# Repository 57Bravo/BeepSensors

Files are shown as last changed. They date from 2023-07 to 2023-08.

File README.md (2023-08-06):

# BeepBerry Sensors Carrier

Integrates UBlox GPS, IMU/MAG, BARO, and buzzer.

REV: - was built and verified on a BeepBerry, however, there are some problems with it:
* During integration, I blew the TPS61030 boost converter IC. I ordered a couple from Mouser and was able to replace it, fixing the device. I was not able to identify what caused the failure in that IC though.
* The buzzer isn't very loud, but can be used as a generic audio device. It's kind of neat that you can use espeak to do text to speech on such a small piezo.
* The GPS antenna doesn't have a large enough ground plane, so 3D fixes break often. It's still usable, just not what you'd expect from a UBlox devkit.
* GPS acquisition eats the battery, but you can control the GPS reset line to disable it to save power. 



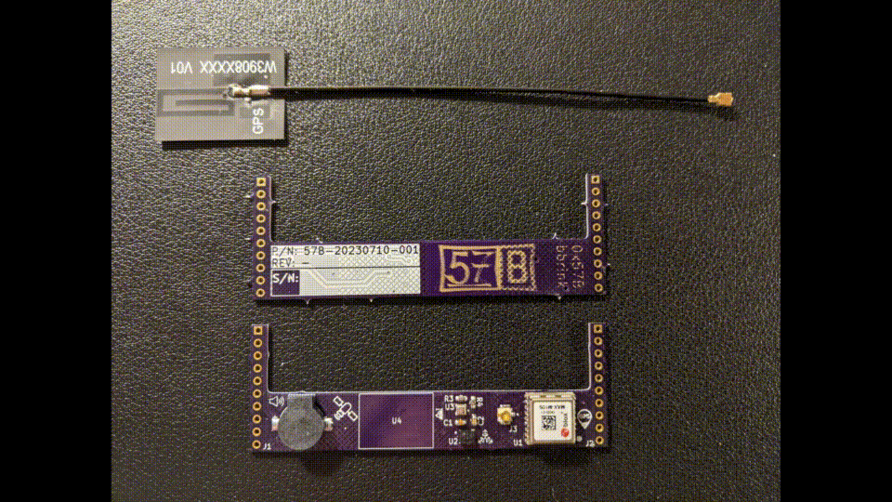
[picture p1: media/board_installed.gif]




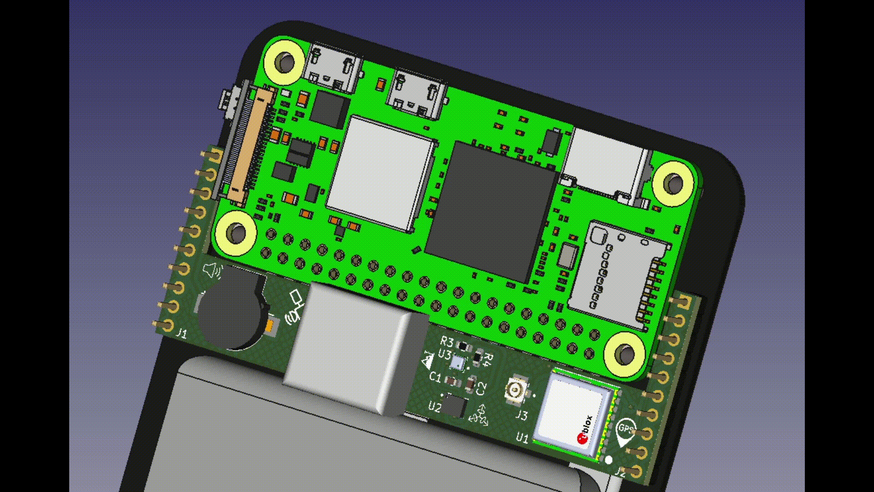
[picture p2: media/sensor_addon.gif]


## Using the buzzer

### Simple Tones
```
import RPi.GPIO as GPIO
import time
import random

GPIO.setmode(GPIO.BCM)
GPIO.setup(13, GPIO.OUT)

pwm = GPIO.PWM(13, 57)
pwm.start(10)

for i in range(random.randint(0,10)):
  pwm.ChangeFrequency(random.randint(1,10000))
  time.sleep(random.random())
pwm.stop()
```

### ALSA

In `/boot/config.txt`, add:

```
dtoverlay=audremap,enable_jack=on
dtoverlay=pwm-2chan,pin2=13,func2=4
```

then use anything that uses a sound card, IE:

`espeak "SAY SOMETHING"`

`aplay "some.wav"`

## Using GPS PPS

In `/boot/config.txt`, add:

`dtoverlay=pps-gpio,gpiopin=16`

This will allow you to use gpsd with `/dev/pps0`.

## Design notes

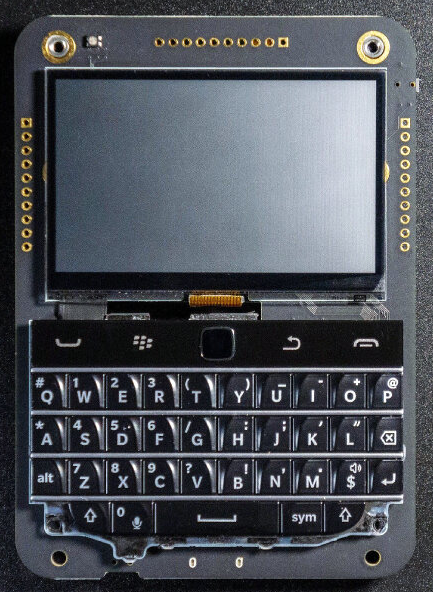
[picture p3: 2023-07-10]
media/beepberry.png

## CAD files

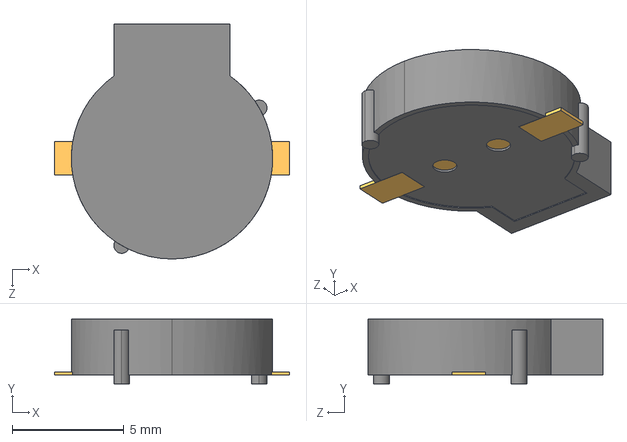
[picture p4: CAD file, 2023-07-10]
pcb/beepsensors/3d_models/CUI_DEVICES_CBT-09427-SMT-TR.step
10.5 x 2.90 x 10.5 mm

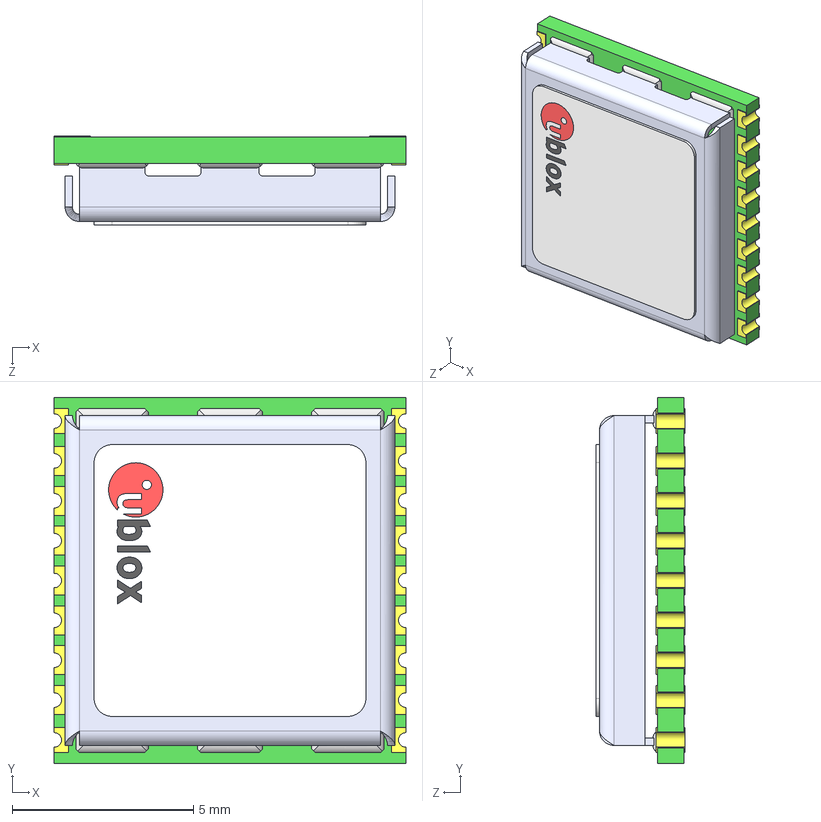
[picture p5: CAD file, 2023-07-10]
pcb/beepsensors/3d_models/max-7.step
9.70 x 10.1 x 2.47 mm
u-blox_MAX_label_Default
Shield
MAX_PCB

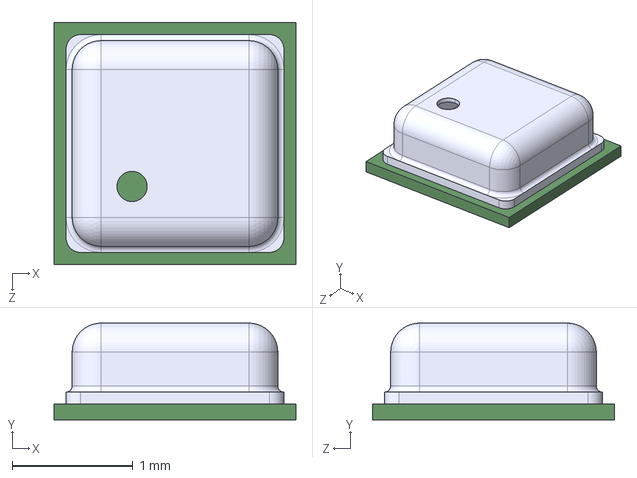
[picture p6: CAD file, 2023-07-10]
pcb/beepsensors/3d_models/BMP388.step
2.00 x 0.8 x 2.00 mm

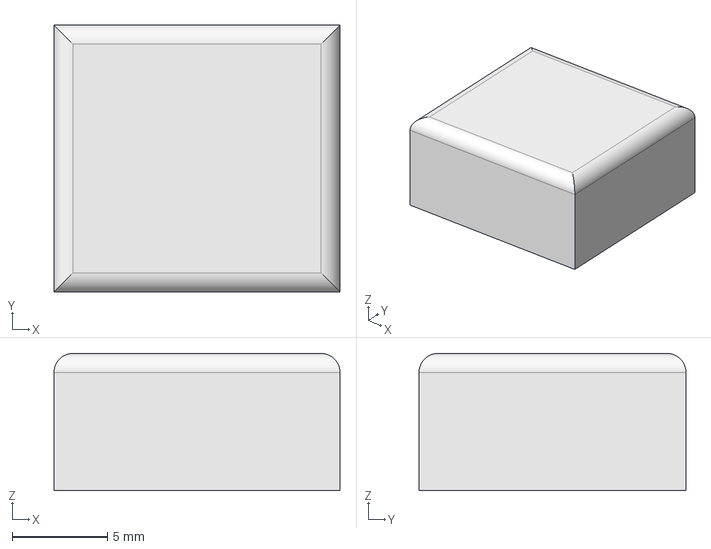
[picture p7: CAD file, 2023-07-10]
pcb/beepsensors/3d_models/gpsmod1315.step
15.0 x 14.0 x 7.20 mm

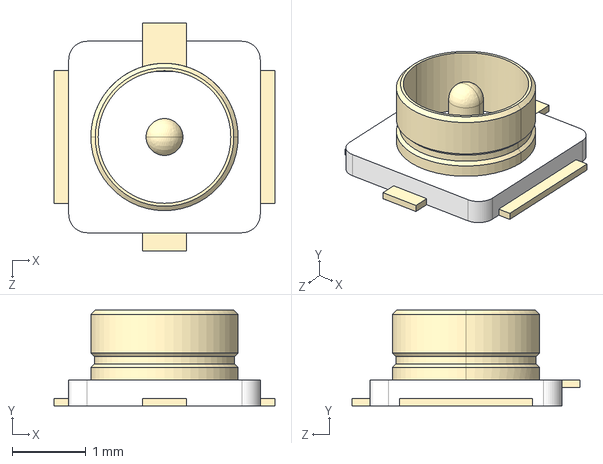
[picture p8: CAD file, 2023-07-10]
pcb/beepsensors/3d_models/CONUFL001-SMD-T.step
3.00 x 1.30 x 3.10 mm

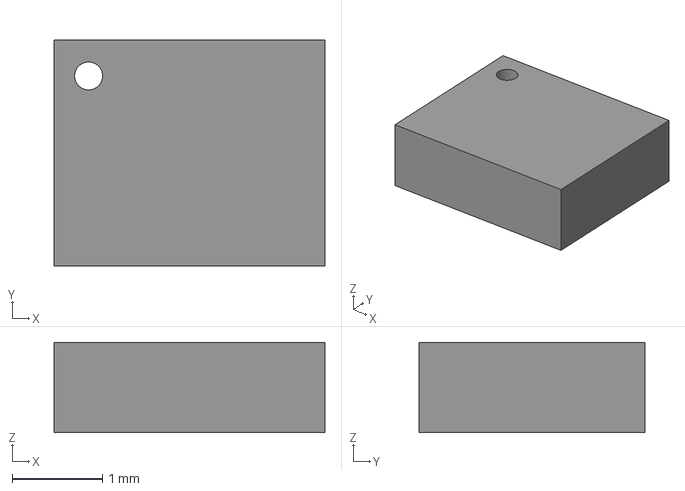
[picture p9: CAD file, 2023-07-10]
pcb/beepsensors/3d_models/bmx160.step
3.00 x 2.50 x 1.00 mm

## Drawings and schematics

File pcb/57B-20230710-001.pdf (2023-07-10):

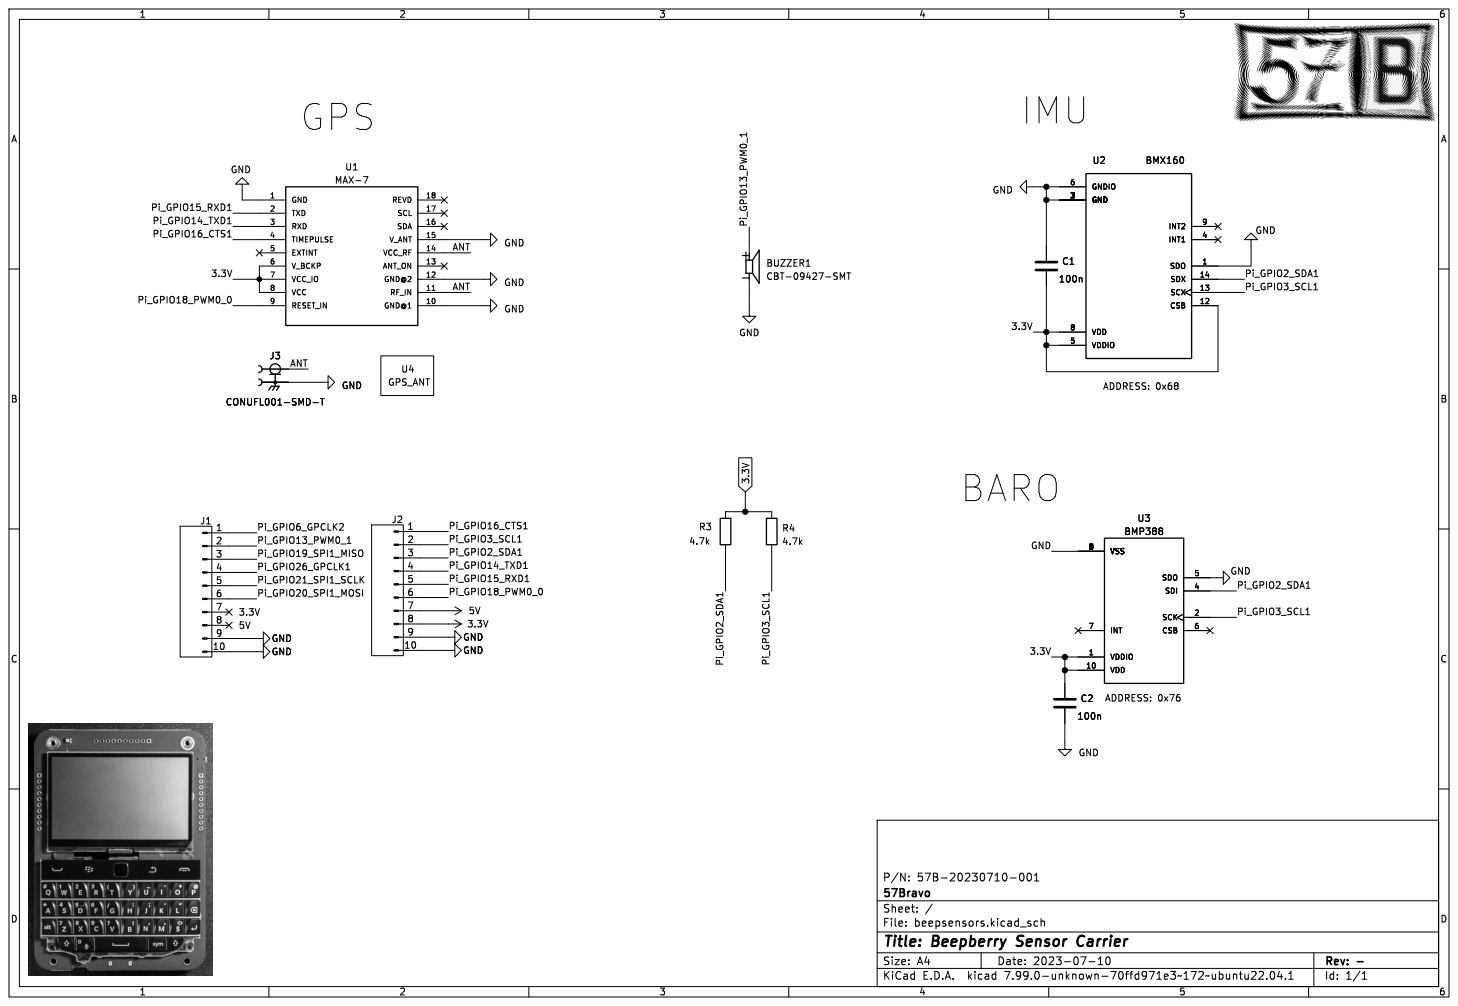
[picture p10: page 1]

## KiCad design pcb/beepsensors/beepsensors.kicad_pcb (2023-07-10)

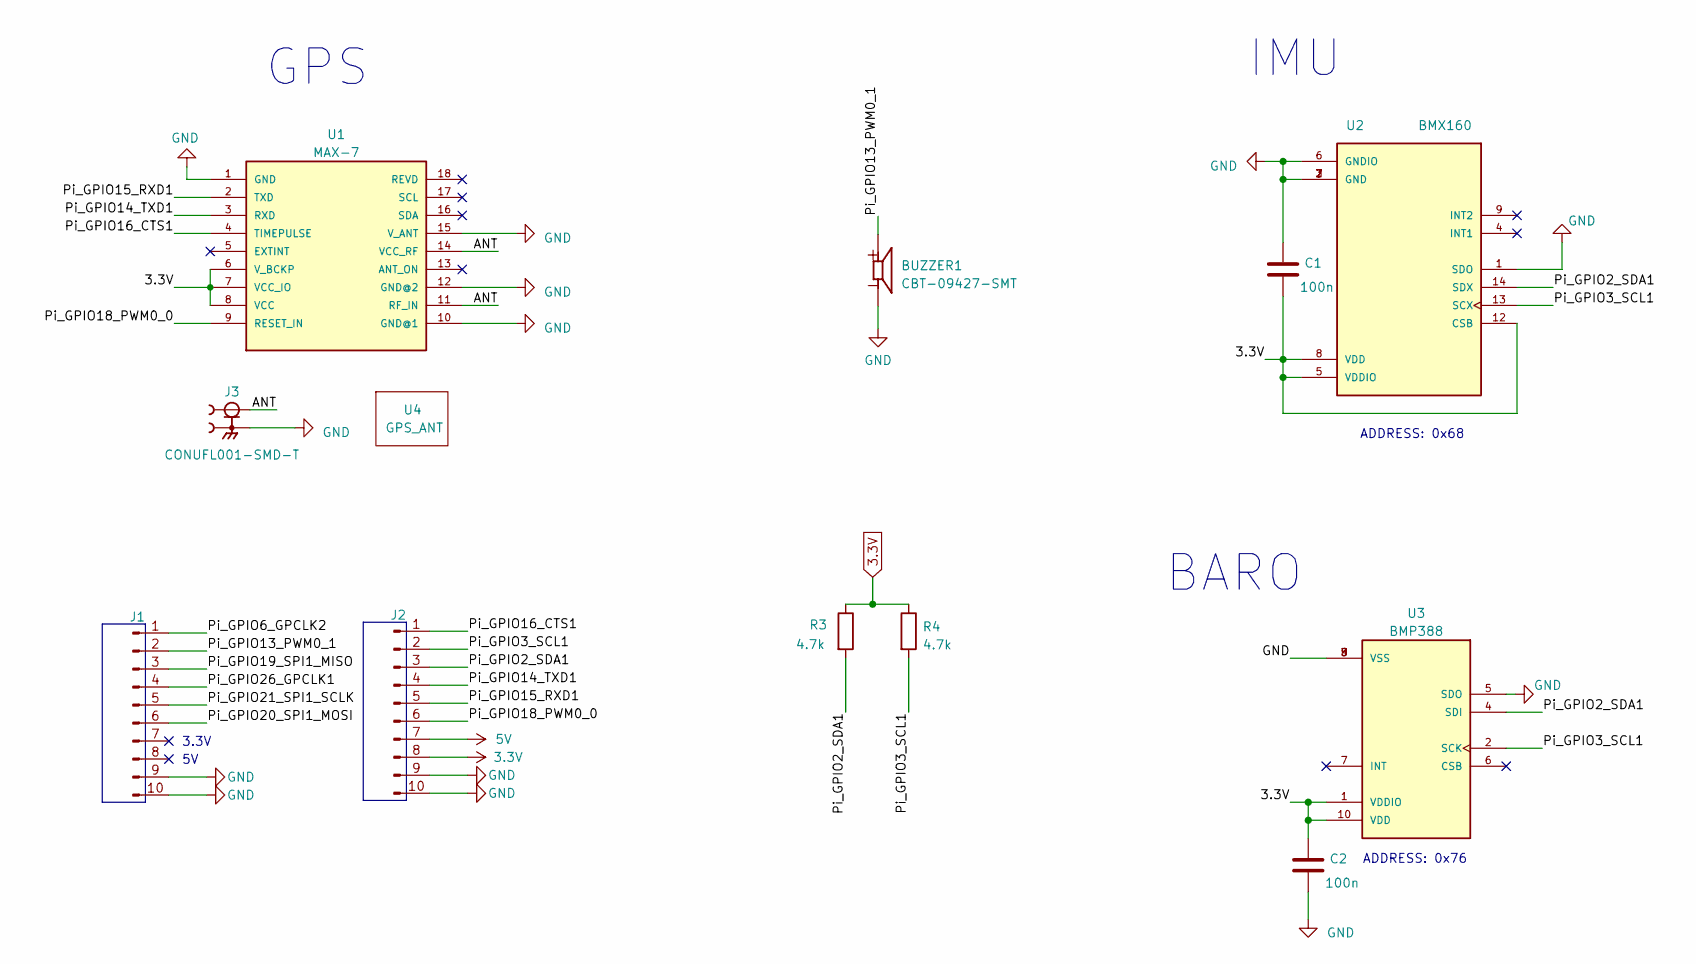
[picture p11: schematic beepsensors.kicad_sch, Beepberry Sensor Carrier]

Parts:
BUZZER1: CBT-09427-SMT; CUI_CBT-09427-SMT
C1, C2: 100n; C_0603_1608Metric
J1, J2: Conn_01x10_Pin; PinHeader_1x10_P2.54mm_Vertical
J3: CONUFL001-SMD-T; LINX_CONUFL001-SMD-T; PARTREV B
R3, R4: 4.7k; R_0603_1608Metric
U1: MAX-7; GPS18P-SMD-1.1-10X9.6MM; MPN MAX-7Q-0
U2: BMX160; PQFN50P250X300X100-14N; PARTREV 1.2
U3: BMP388; PQFN50P200X200X80-10N; PARTREV 1.1
U4: GPS_ANT; gps_ant

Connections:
3.3V: C1.2, C2.1, J2.8, R3.1, R4.1, U1.6 (V_BCKP), U1.7 (VCC_IO), U1.8 (VCC), U2.5 (VDDIO), U2.8 (VDD), U2.12 (CSB), U3.1 (VDDIO), U3.10 (VDD)
5V: J2.7
/ANT: J3.1, U1.11 (RF_IN), U1.14 (VCC_RF)
/Pi_GPIO2_SDA1: J2.3, R3.2, U2.14 (SDX), U3.4 (SDI)
/Pi_GPIO3_SCL1: J2.2, R4.2, U2.13 (SCX), U3.2 (SCK)
/Pi_GPIO6_GPCLK2: J1.1
/Pi_GPIO13_PWM0_1: BUZZER1.P, J1.2
/Pi_GPIO14_TXD1: J2.4, U1.3 (RXD)
/Pi_GPIO15_RXD1: J2.5, U1.2 (TXD)
/Pi_GPIO16_CTS1: J2.1, U1.4 (TIMEPULSE)
/Pi_GPIO18_PWM0_0: J2.6, U1.9 (RESET_IN)
/Pi_GPIO19_SPI1_MISO: J1.3
/Pi_GPIO20_SPI1_MOSI: J1.6
/Pi_GPIO21_SPI1_SCLK: J1.5
/Pi_GPIO26_GPCLK1: J1.4
GND: BUZZER1.M, C1.1, C2.2, J1.9, J1.10, J2.9, J2.10, J3.2, J3.3, U1.1 (GND), U1.10 (GND@1), U1.12 (GND@2), U1.15 (V_ANT), U2.1 (SDO), U2.2 (GND), U2.3 (GND), U2.6 (GNDIO), U2.7 (GND), U3.3 (VSS), U3.5 (SDO), U3.8 (VSS), U3.9 (VSS)

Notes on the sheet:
ADDRESS: 0x76
BARO
ADDRESS: 0x68
IMU
3.3V
GPS

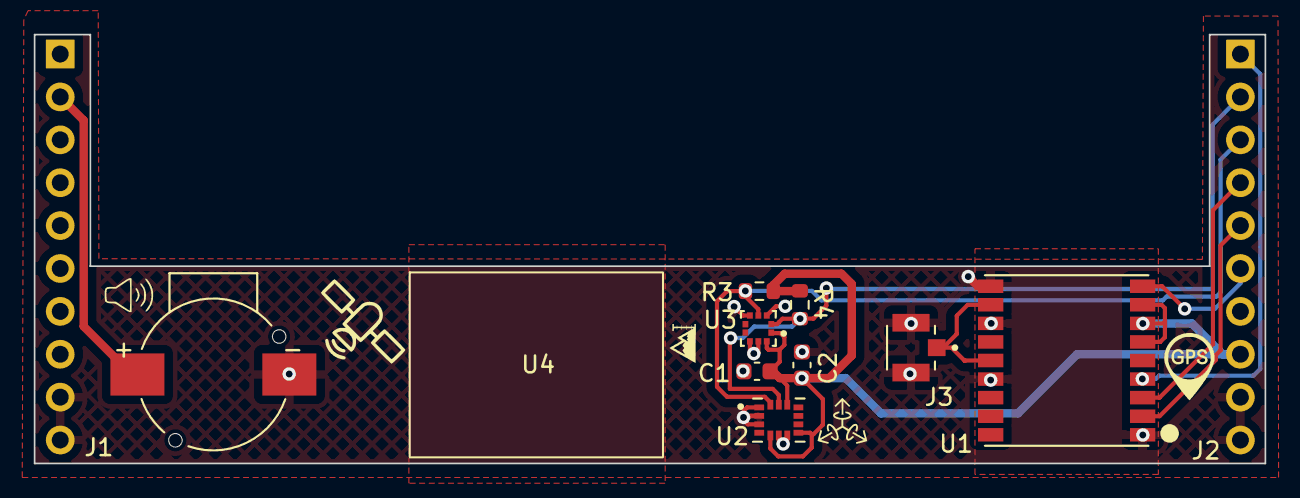
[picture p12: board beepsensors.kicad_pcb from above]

Board: 2 copper layers, 72.9 x 25.4 mm, 12 parts (0 on the bottom side), 10 nets.

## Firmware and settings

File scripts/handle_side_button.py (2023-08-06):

#!/usr/bin/python3
##################

import RPi.GPIO as GPIO
import time
import os

# const's

## button
GPIO_SIDE_BUTTON = 17
BUTTON_PRESSED = 0
BUTTON_RELEASED = True
POLL_TIMEOUT_SECS = 0.1

## display
SCREEN_ON = True
SCREEN_DEV = '/sys/class/graphics/fb1'
KEYBOARD_DEV = '/sys/class/input/input0'
TOUCHPAD_DEV = '/sys/class/input/input1'
CONSOLE_DEV = '/dev/tty1'
SILENCE = ' > /dev/null 2>&1'

## commands, relies on sysfs and escap sequences

### blank the screen
SCREEN_OFF_CMD_1 = 'bash -c "echo 1 > ' + SCREEN_DEV + '/blank"' + SILENCE
### disable
SCREEN_OFF_CMD_2 = 'echo 1 > ' + SCREEN_DEV + '/state'

### disable keyboard
KEYBOARD_DISABLE = 'echo 1 > ' + KEYBOARD_DEV + '/inhibited'
### disable touchpad
TOUCHPAD_DISABLE = 'echo 1 > ' + TOUCHPAD_DEV + '/inhibited'

### show the screen
SCREEN_ON_CMD_1 = 'bash -c "echo 0 > ' + SCREEN_DEV + '/blank"' + SILENCE
### enable
SCREEN_ON_CMD_2 = 'echo 0 > ' + SCREEN_DEV + '/state'

### enable keyboard
KEYBOARD_ENABLE = 'echo 0 > ' + KEYBOARD_DEV + '/inhibited'
### enable touchpad
TOUCHPAD_ENABLE = 'echo 0 > ' + TOUCHPAD_DEV + '/inhibited'

# setup the side button with a pull-up
GPIO.setmode(GPIO.BCM)
GPIO.setup(GPIO_SIDE_BUTTON, GPIO.IN, pull_up_down=GPIO.PUD_UP)

# poll the button
while True:

  # wait for a button press
  if GPIO.input(GPIO_SIDE_BUTTON) == BUTTON_PRESSED:

    # track the release
    if BUTTON_RELEASED:
      BUTTON_RELEASED = False

      # ON to OFF
      if SCREEN_ON:
        SCREEN_ON = False
        os.system(SCREEN_OFF_CMD_1)
        os.system(SCREEN_OFF_CMD_2)
        os.system(KEYBOARD_DISABLE)
        os.system(TOUCHPAD_DISABLE)
      # OFF to ON
      else:
        SCREEN_ON = True
        os.system(SCREEN_ON_CMD_1)
        os.system(SCREEN_ON_CMD_2)
        os.system(KEYBOARD_ENABLE)
        os.system(TOUCHPAD_ENABLE)

  else:
    BUTTON_RELEASED = True

  # don't thrash
  time.sleep(POLL_TIMEOUT_SECS)

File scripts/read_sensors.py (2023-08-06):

#!/usr/bin/python3
##################

import smbus
import time
from bmp388 import BMP388_I2C
from bmx160 import BMX160
import gps

gpsd = gps.gps(mode=gps.WATCH_ENABLE)

i2c_1 = smbus.SMBus(1)
bmp388 = BMP388_I2C(i2c_1)

bmx160 = BMX160(1)
bmx160.begin()

# clear screen
print('\033[2J')

while True:

  # read gps before clearing the screen, since it blocks
  gpsd.read()

  # clear the screen
  print('\033[2J')

  # goto cursor 0,0
  print('\033[0;0H')

  # print gps
  #if (gps.MODE_SET & gpsd.valid):

  print('Mode: %s(%d)\n' %
       (('Invalid', 'NO_FIX', '2D', '3D')[gpsd.fix.mode],
       gpsd.fix.mode), end='')

  #if gps.TIME_SET & gpsd.valid:
  print('Time: ' + str(gpsd.fix.time))
  #else:
  #  print('Time: ---')

  if ((gps.isfinite(gpsd.fix.latitude) and
    gps.isfinite(gpsd.fix.longitude))):
    print('Lat %.8f' % (gpsd.fix.latitude))
    print('Lon %.8f' % (gpsd.fix.longitude))
  else:
    print('Lat: ---')
    print('Lon: ---')

  # print baro
  print('')
  print('Altitude (m): ' + '{:10.3f}'.format(bmp388.readAltitude()))
  print('Pressure (hPa): ' + '{:10.3f}'.format(bmp388.readPressure()/100.0))
  print('Temperature (C): ' + '{:10.3f}'.format(bmp388.readTemperature()))

  # print imu
  print('')
  data = bmx160.get_all_data()
  print('ACC: ' + '{:10.3f}'.format(data[6]) + '{:10.3f}'.format(data[7]) + '{:10.3f}'.format(data[8]))
  print('GYR: ' + '{:10.3f}'.format(data[3]) + '{:10.3f}'.format(data[4]) + '{:10.3f}'.format(data[5]))
  print('MAG: ' + '{:10.3f}'.format(data[0]) + '{:10.3f}'.format(data[1]) + '{:10.3f}'.format(data[2]))

  time.sleep(0.1)

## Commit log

2023-07-10 export for GitHub
    [BMP388.step, CONUFL001-SMD-T.step, CUI_DEVICES_CBT-09427-SMT-TR.step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]
2023-07-25 add image of populated board
2023-07-27 added photos of board installed
